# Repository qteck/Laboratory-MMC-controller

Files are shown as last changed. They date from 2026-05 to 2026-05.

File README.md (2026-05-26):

# Laboratory MMC controller

This system drives series-connected stack topologies. The core of the system is the controller board that implements STM32 for flow control and data processing. The board provides local and remote HMI, monitoring points for voltage and current, and additional functions such as PWM channels or a power supply terminal.

The system provides extended functionality through additional shields, such as a data acquisition shield for producing or reconstructing digital signals, a power supply board, and an encoder and display for local user input.

Functions: 
- Submodule UART Link 
- USB Data Link
- Voltage Monitoring 
- Current Monitoring 

Additional Functions: 
- PWM Channels
- 5V/3V3 Power Sources

PCB Shields:
- Data Acquisition (signal viewer)
- Power Supply (power booster)
- Encoder
- Display

## Ideal Laboratory Submodule

For the controller to be able to efficiently drive the submodules, the submodules need to implement a full-duplex UART communication protocol and accurate time metering. The used MCU also has to be capable of producing the control waveforms, such as the modulation sine wave and carrier triangular wave, for producing the control switching patterns. The time synchronization setting is essential for effective functioning and should be optimized by algorithmic sweeps through the stack. However, for simplicity and versatility, it is recommended to implement a synchronization input, giving an extra synchronization option, for example, for debugging purposes.

The submodules should be autonomous and function as decentralized units, implementing functions such as current and voltage metering on board, local capacitor management on board, and the submodule algorithm to define the stack behaviour, describing functions such as data propagation, frequency adjustment, scheduled events, and fault handling.

### Minimal Submodule Design

The minimal submodule design establishes the conversion features only: an MCU with half-bridge or full-bridge capabilities and a capacitor on board that connects over UART and synchronizes over an external pin. The capacitors can then be directly charged from the controller board, leaving out all the complex control problems.

## Simple System Architecture
System Architecture
## PCB Assembly
PCB Assembly
## Detailed System Architecture
Detailed System Architecture
## Real System View
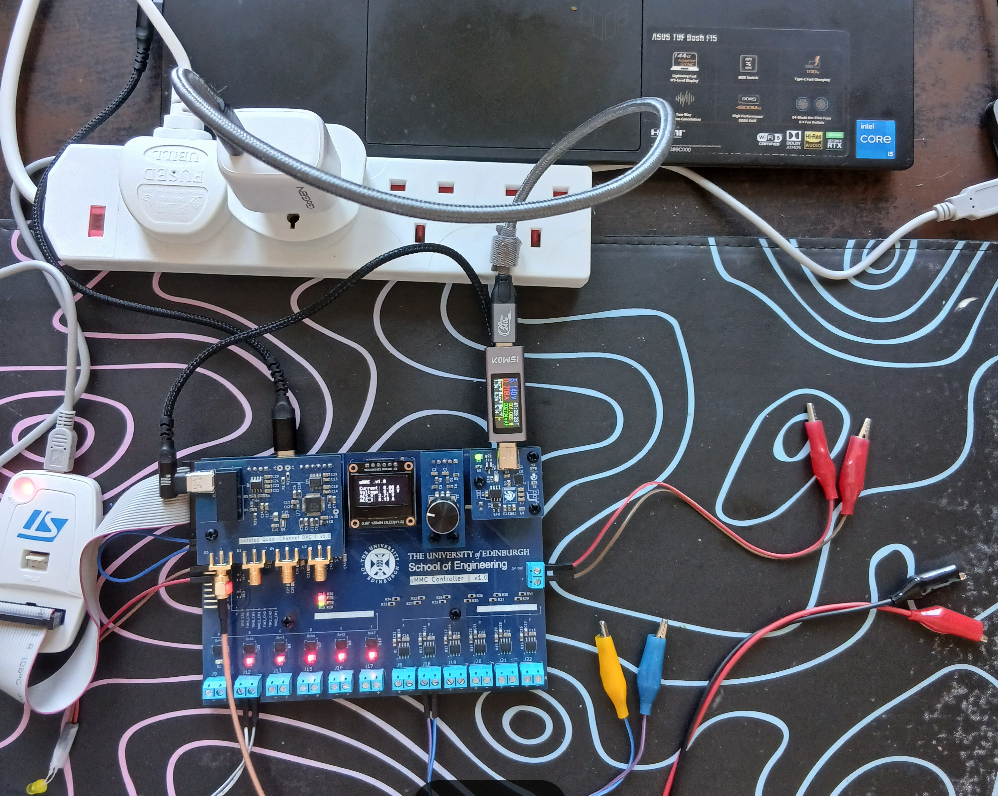
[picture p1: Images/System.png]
Real System View

## Model System View
Model System View

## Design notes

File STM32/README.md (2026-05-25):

# STM32H725VGTx

## Pinout

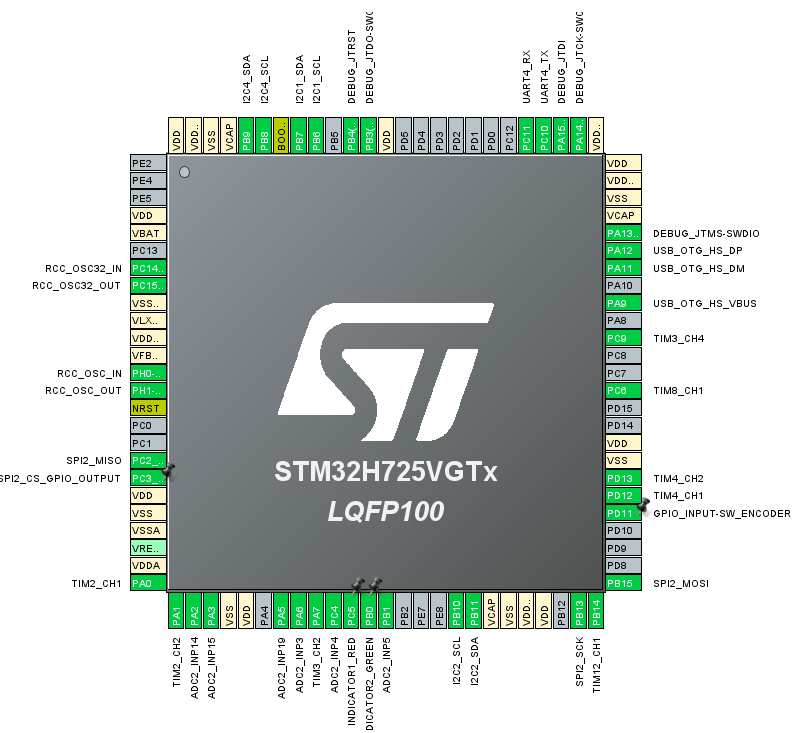
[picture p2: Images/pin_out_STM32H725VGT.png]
STM32H725VGTx pinout


## References

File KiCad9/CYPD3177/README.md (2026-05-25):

# Power Supply

The purpose of this module is to provide 5V@1A. The power negotiation is managed by the CYPD3177, which negotiates the power over the CC lines and triggers an alert if the negotiation for the selected power scenario fails.

The module features a load switch made of two back-to-back PMOS transistors, soft start, and inductive kickback protection.

## Improvement: 
To improve the modular USB power supply, a switchable display showing power consumption could be implemented, as well as means for remote power monitoring purposes over some digital protocol.

## Front Side 
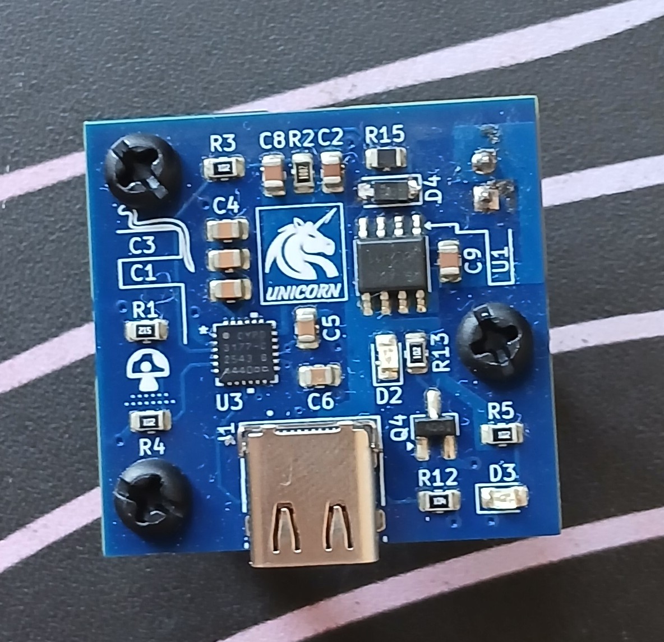
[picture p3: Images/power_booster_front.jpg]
controller front

## Back Side
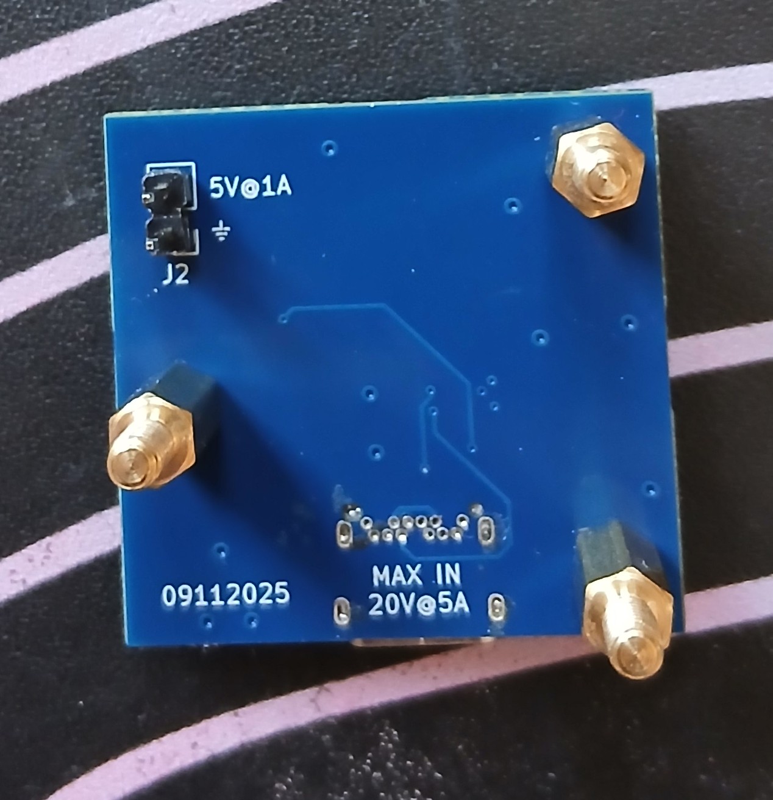
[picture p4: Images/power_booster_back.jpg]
controller back


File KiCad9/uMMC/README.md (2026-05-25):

# Laboratory MMC controller
The purpose of the controller is to drive series-connected stack topologies. This is achieved through a UART data connection, which is responsible for communicating variables such as the modulation index and submodule ID.

To achieve accurate switching, the submodules must be capable of real-time synchronisation and local generation of synchronous triangular carrier waveforms and sinusoidal modulation waveforms.

While the triangular carrier waveform is synchronised and common to all submodules, the modulation waveform has different amplitudes for each submodule. These amplitude offsets are calculated on the controller board and propagated through the UART data connection.

## Time Synchronisation  

### Time-Tuning Algorithm  

The time synchronisation can be achieved simply by propagating the reference time through the stack over UART. These times can then be compared on the controller, and the propagation delays can be compensated for.

### Synchronisation Signal  

Alternatively, for a simple implementation and high accuracy, the submodules can feature a synchronisation pin that would start the time, for example, on logic high.

## Initialisation

The stack is expected to be initialised by running firmware on the submodules that firstly passes the data sent down the chain, and secondly iterates a variable that counts the submodules.

Based on the number of submodules and symmetry of the arms, the number of modules per arm is obtained by division of two.

The offset values of the modulation index are then calculated based on the number of submodules present in the upper and lower arm. These offsets are then distributed over UART to each of the submodules.

## Front Side 
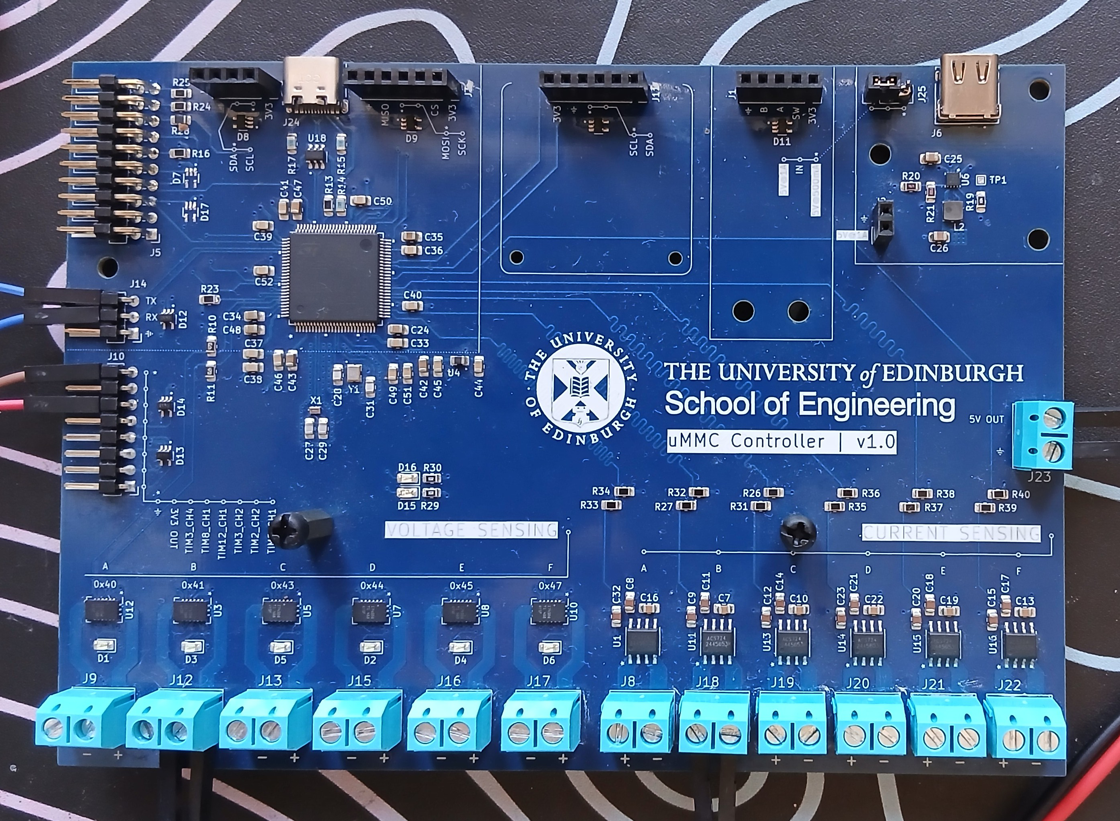
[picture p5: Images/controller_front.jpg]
controller front

## Back Side
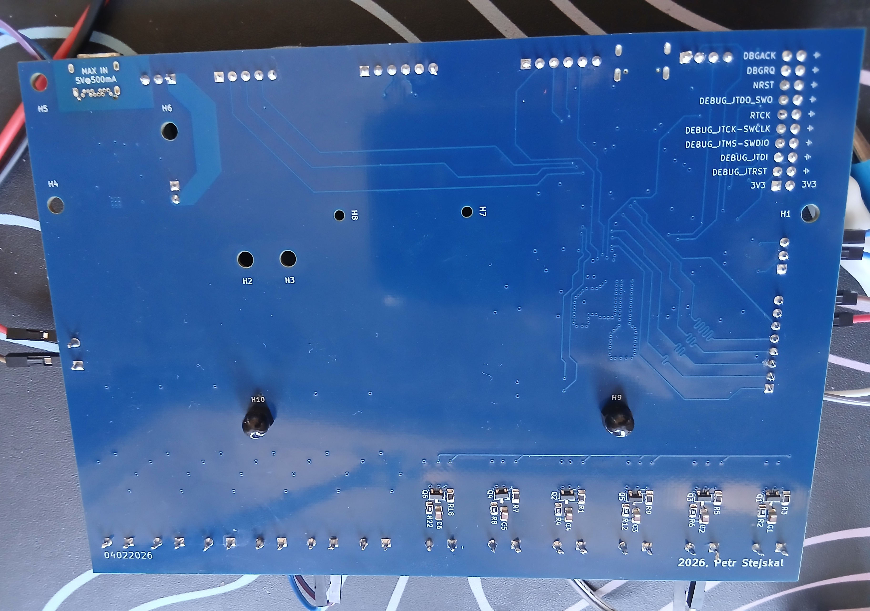
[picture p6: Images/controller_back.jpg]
controller back


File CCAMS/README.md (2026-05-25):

# Cloud Control and Monitoring System (CCAMS)

This is a cloud control and monitoring system implementing basic functionality. It uses the Web Serial API in Chrome.

Includes:
- jQuery
- Bootstrap
- Popper.js
- Web Serial API

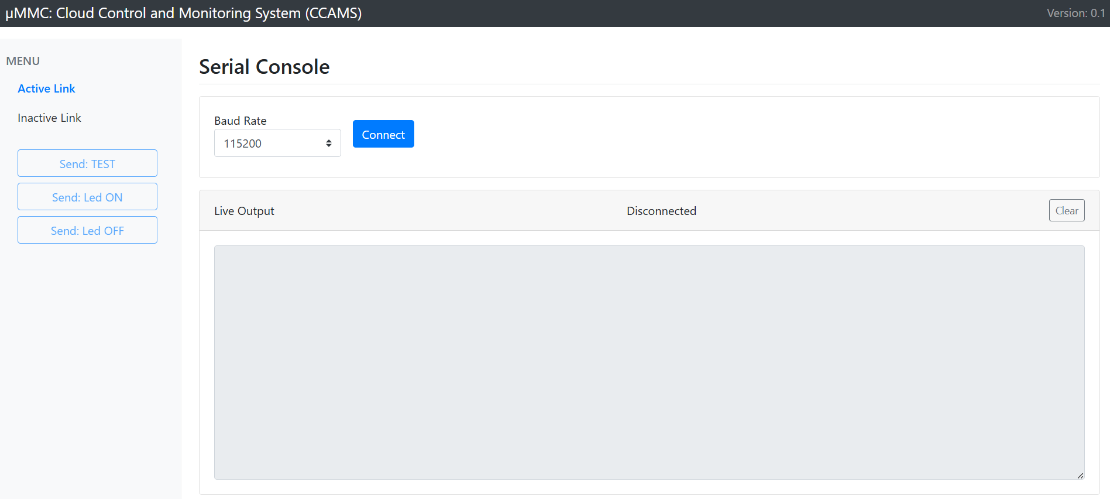
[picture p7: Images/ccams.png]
CCAMS


## References

- MDN Web Docs: Web Serial API  
  https://developer.mozilla.org/en-US/docs/Web/API/Web_Serial_API

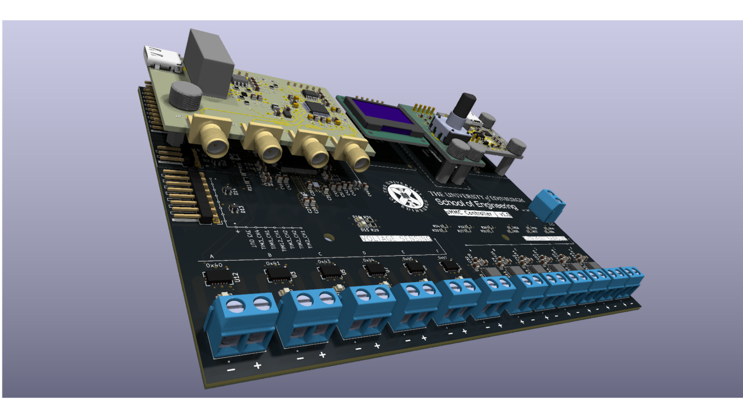
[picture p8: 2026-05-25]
KiCad9/uMMC/Images/900e9da2-3d48-431e-bf87-90206d79b5b3.png

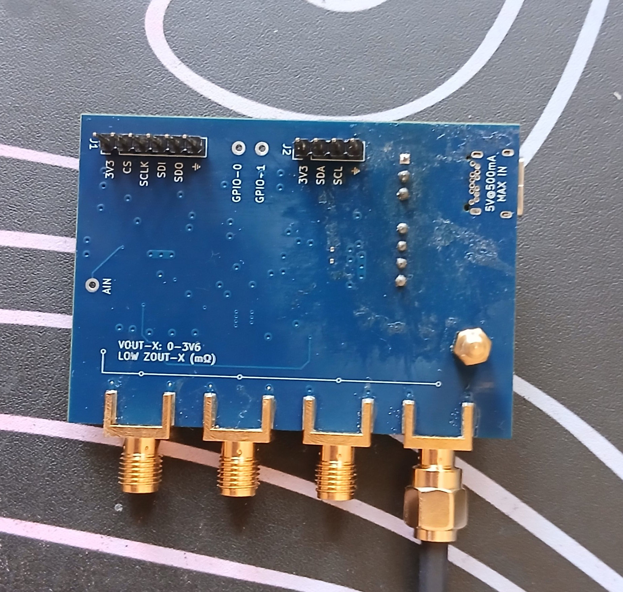
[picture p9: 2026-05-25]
Images/acquisition_back.jpg

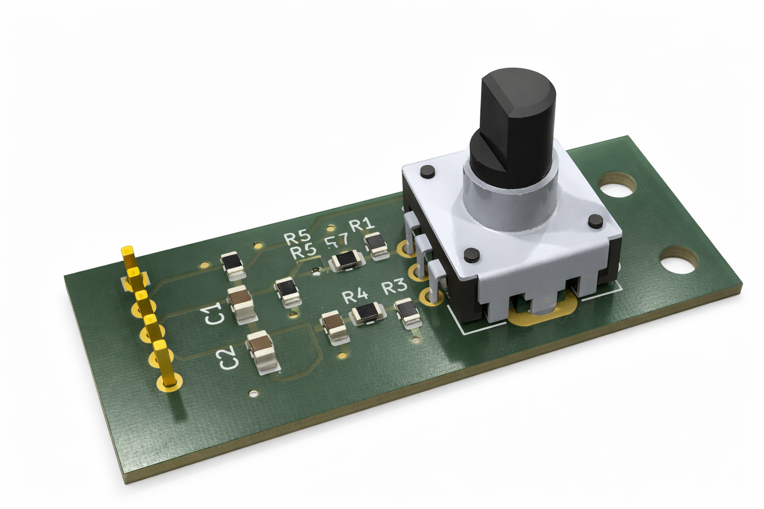
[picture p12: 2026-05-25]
KiCad9/uMMC/Images/encoder2.png

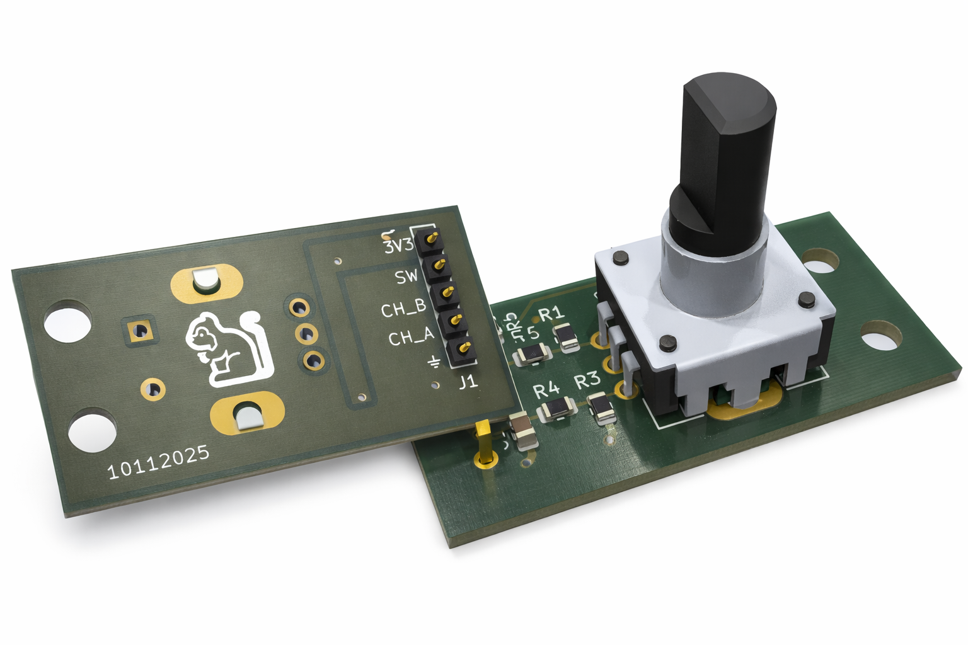
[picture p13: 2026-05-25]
KiCad9/uMMC/Images/encoder.png

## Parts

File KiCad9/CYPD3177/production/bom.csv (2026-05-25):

Designator | Footprint | Quantity | Value | LCSC Part #
C1, C3 | 1210 | 2 | 0.1u | C304007
C10 | 1210 | 1 | 3.3u | C575409
C2, C8, C9 | 1210 | 3 | 1u | C382212
C4 | 1210 | 1 | 1u | C304007
C5, C6 | 1210 | 2 | 330p | C5144765
D2 | 0805 | 1 | 5mA | C5349939
D3 | 0805 | 1 | 20mA | C84260
D4 | D_SOD-123FL | 1 | 10V | C551630
J1 | GCT_USB4056-03-A_REVA2 | 1 | USB4056-03-A_REVA2
J2, J3 | PinHeader_1x02_P2.54mm_Vertical | 2 | Conn_01x02 | C27985187
Q1, Q3 | SOT-23_Handsoldering | 2 | 2305-B | C22362821
Q4 | SOT-23_Handsoldering | 1 | NTR4503NT1G | C94763
R1, R4, R7, R8 | 1210 | 4 | 2k | C396544
R10, R15 | 1210 | 2 | 49.9k | C422286
R11, R13, R3 | 1210 | 3 | 1k | C3152371
R12 | 1210 | 1 | 100K | C910966
R14 | 1210 | 1 | 2.21K | C174501
R2 | 1210 | 1 | 10k | C3018181
R9 | 1210 | 1 | 0 | C3018186
RV1, RV2, RV3, RV4 | Potentiometer_Bourns_3296W_Vertical | 4 | 25K | C55264
TP1, TP2, TP3 | TestPoint_THTPad_2.0x2.0mm_Drill1.0mm | 3 | ~
TP10, TP11, TP12, TP4, TP5, TP6, TP7, TP8, TP9 | TestPoint_THTPad_2.0x2.0mm_Drill1.0mm | 9 | TestPoint
U1 | AO4805-MS | 1 | AO4805-MS | C3008143
U3 | QFN24_CYPD3177_INF | 1 | CYPD3177-24LQXQ | C2959321

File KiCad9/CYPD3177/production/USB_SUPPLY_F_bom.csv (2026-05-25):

Designator | Footprint | Quantity | Value | LCSC Part #
C1, C3, C4 | 0805 | 3 | 0.1u
C2 | 0805 | 1 | 3.3u
C5, C6 | 0805 | 2 | 330p
C8, C9 | 0805 | 2 | 1u
D2 | 0805 | 1 | 5mA
D3 | 0805 | 1 | 20mA
D4 | D_SOD-123 | 1 | 10V
J1 | GCT_USB4056-03-A_REVA2 | 1 | USB4056-03-A_REVA2
J2 | PinHeader_1x02_P2.54mm_Vertical | 1 | Conn_01x02
Q4 | SOT-23_Handsoldering | 1 | PJA3406_R1_00001
R1 | 0805 | 1 | 5k1
R12 | 0805 | 1 | 100K
R13, R3, R4, R5 | 0805 | 4 | 1K
R15 | 0805 | 1 | 49.9k
R2 | 0805 | 1 | 10k
U1 | SOP-8_3.9x4.9mm_P1.27mm | 1 | AO4805-MS | C3008143
U3 | QFN24_CYPD3177_INF | 1 | CYPD3177-24LQXQ | C2959321

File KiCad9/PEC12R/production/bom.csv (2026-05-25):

Designator | Footprint | Quantity | Value | LCSC Part #
C1, C2 | 0805 | 2 | 0.01u
J1 | PinHeader_1x05_P2.54mm_Vertical | 1 | Conn_01x05_Pin
R1, R2, R3, R4, R5 | 0805 | 5 | 10k
S1 | XDCR_PEC12R-4220F-S0024 | 1 | PEC12R-4220F

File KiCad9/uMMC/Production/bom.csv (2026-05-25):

Designator | Footprint | Quantity | Value | LCSC Part #
C1, C11, C12, C14, C15, C17, C18, C2, C20, C21, C23, C3, C32, C4, C5, C6, C8, C9 | 0805 | 18 | 0.1u
C10, C13, C16, C19, C22, C7 | 0805 | 6 | 1n
C24, C42, C43 | 0805 | 3 | 1u
C25 | 0805 | 1 | 10u
C26 | 0805 | 1 | 22u
C27, C29 | 0805 | 2 | 8p
C28, C31 | 0805 | 2 | 10p
C33, C36, C37, C38, C39, C40, C41, C44, C45, C46, C49, C50, C51, C52 | 0805 | 14 | 100n
C34, C48 | 0805 | 2 | 2.2u
C35, C47 | 0805 | 2 | 4.7u
D1, D15, D16, D2, D3, D4, D5, D6 | 0805 | 8 | 20mA
D10, D11, D12, D13, D14, D17, D7, D8, D9 | ESDALC6V1W5 | 9 | ESDA6V1W5
J1 | PinSocket_1x05_P2.54mm_Vertical | 1 | ENCODER
J10 | PinHeader_1x08_P2.54mm_Horizontal | 1 | PWM
J11 | PinSocket_1x06_P2.54mm_Vertical | 1 | I2C DISPLAY
J12, J13, J15, J16, J17, J18, J19, J20, J21, J22, J23, J8, J9 | CUI_TB002-500-02BE | 13 | TB002-500-02BE
J14 | PinHeader_1x03_P2.54mm_Horizontal | 1 | SM_UART
J2 | PinSocket_1x02_P2.54mm_Vertical | 1 | 5V@1A
J24 | GCT_USB4105-GF-A-SMD | 1 | USB4105-GF-A
J25 | PinHeader_1x03_P2.54mm_Vertical | 1 | Conn_01x03_Pin
J3 | PinSocket_1x06_P2.54mm_Vertical | 1 | SPI_DAC
J4 | PinSocket_1x04_P2.54mm_Vertical | 1 | I2C_DAC
J5 | PinHeader_2x10_P2.54mm_Horizontal | 1 | JTAG_20PIN
J6 | GCT_USB4056-03-A_REVA2 | 1 | USB4056-03-A_REVA2
L2 | IND_VLS3012CX-2R2M-1 | 1 | 2.2u
Q1, Q2, Q3, Q4, Q5, Q6 | SOT-23_DMP2123L_DIO | 6 | DMP2123L-7
R1, R16, R18, R23, R24, R25, R26, R27, R3, R31, R32, R33, R34, R35, R36, R37, R38, R39, R40, R5, R7, R9 | 0805 | 22 | 10k
R10, R11 | 0805 | 2 | 4.7k
R12, R2, R22, R29, R30, R4, R6, R8 | 0805 | 8 | 1K
R13 | 0805 | 1 | 33k
R14 | 0805 | 1 | 68k
R15, R17 | 0805 | 2 | 5.1k
R19 | 0805 | 1 | 100K
R20 | 0805 | 1 | 470K
R21 | 0805 | 1 | 150K
R28 | 0805 | 1 | 0
TP1 | TestPoint_Pad_1.0x1.0mm | 1 | PG
U1, U11, U13, U14, U15, U16 | ACS724LLCTR_2P5AB_T | 6 | ACS724LLCTR-2P5AB-T
U10, U12, U3, U5, U7, U8 | INA745BQWRELRQ1 | 6 | INA745BQWRELRQ1CT
U18 | USBLC6-2SC6 | 1 | USBLC6-2SC6
U4 | BLM21_TALL_MUR | 1 | BLM21HE601SN1L
U6 | DSG0008A_NV | 1 | TPS62162QDSGTQ1
U9 | LQPF_25VGT3_STM | 1 | STM32H725VGT3
X1 | XTAL_ECS-.327-7-16-C-TR | 1 | 32.768 kHz
Y1 | XTAL_ABM10AIG-24.000MHZ-8-3Z-T3 | 1 | 24 MHz

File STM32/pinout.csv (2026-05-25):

Position | Name | Type | Signal | Label
1 | PE2 | I/O
2 | PE4 | I/O
3 | PE5 | I/O
4 | VDD | Power
5 | VBAT | Power
6 | PC13 | I/O
7 | PC14-OSC32_IN | I/O | RCC_OSC32_IN
8 | PC15-OSC32_OUT | I/O | RCC_OSC32_OUT
9 | VSSSMPS | Power
10 | VLXSMPS | Power
11 | VDDSMPS | Power
12 | VFBSMPS | Power
13 | PH0-OSC_IN | I/O | RCC_OSC_IN
14 | PH1-OSC_OUT | I/O | RCC_OSC_OUT
15 | NRST | Reset
16 | PC0 | I/O
17 | PC1 | I/O
18 | PC2_C | I/O | SPI2_MISO
19 | PC3_C | Output | GPIO_Output | SPI2_CS_GPIO_OUTPUT
20 | VDD | Power
21 | VSS | Power
22 | VSSA | Power
23 | VREF+ | MonoIO
24 | VDDA | Power
25 | PA0 | I/O | TIM2_CH1
26 | PA1 | I/O | TIM2_CH2
27 | PA2 | I/O | ADC2_INP14
28 | PA3 | I/O | ADC2_INP15
29 | VSS | Power
30 | VDD | Power
31 | PA4 | I/O
32 | PA5 | I/O | ADC2_INP19
33 | PA6 | I/O | ADC2_INP3
34 | PA7 | I/O | TIM3_CH2
35 | PC4 | I/O | ADC2_INP4
36 | PC5 | Output | GPIO_Output | INDICATOR1_RED
37 | PB0 | Output | GPIO_Output | INDICATOR2_GREEN
38 | PB1 | I/O | ADC2_INP5
39 | PB2 | I/O
40 | PE7 | I/O
41 | PE8 | I/O
42 | PB10 | I/O | I2C2_SCL
43 | PB11 | I/O | I2C2_SDA
44 | VCAP | Power
45 | VSS | Power
46 | VDDLDO | Power
47 | VDD | Power
48 | PB12 | I/O
49 | PB13 | I/O | SPI2_SCK
50 | PB14 | I/O | TIM12_CH1
51 | PB15 | I/O | SPI2_MOSI
52 | PD8 | I/O
53 | PD9 | I/O
54 | PD10 | I/O
55 | PD11 | Input | GPIO_Input | GPIO_INPUT-SW_ENCODER
56 | PD12 | I/O | TIM4_CH1
57 | PD13 | I/O | TIM4_CH2
58 | VSS | Power
59 | VDD | Power
60 | PD14 | I/O
61 | PD15 | I/O
62 | PC6 | I/O | TIM8_CH1
63 | PC7 | I/O
64 | PC8 | I/O
65 | PC9 | I/O | TIM3_CH4
66 | PA8 | I/O
67 | PA9 | I/O | USB_OTG_HS_VBUS
68 | PA10 | I/O
69 | PA11 | I/O | USB_OTG_HS_DM
70 | PA12 | I/O | USB_OTG_HS_DP
71 | PA13(JTMS/SWDIO) | I/O | DEBUG_JTMS-SWDIO
72 | VCAP | Power
73 | VSS | Power
74 | VDDLDO | Power
75 | VDD | Power
76 | VDD33USB | Power
77 | PA14(JTCK/SWCLK) | I/O | DEBUG_JTCK-SWCLK
78 | PA15(JTDI) | I/O | DEBUG_JTDI
79 | PC10 | I/O | UART4_TX
80 | PC11 | I/O | UART4_RX
81 | PC12 | I/O
82 | PD0 | I/O
83 | PD1 | I/O
84 | PD2 | I/O
85 | PD3 | I/O
86 | PD4 | I/O
87 | PD5 | I/O
88 | VDD | Power
89 | PB3(JTDO/TRACESWO) | I/O | DEBUG_JTDO-SWO
90 | PB4(NJTRST) | I/O | DEBUG_JTRST
91 | PB5 | I/O
92 | PB6 | I/O | I2C1_SCL
93 | PB7 | I/O | I2C1_SDA
94 | BOOT0 | Boot
95 | PB8 | I/O | I2C4_SCL
96 | PB9 | I/O | I2C4_SDA
97 | VCAP | Power
98 | VSS | Power
99 | VDDLDO | Power
100 | VDD | Power

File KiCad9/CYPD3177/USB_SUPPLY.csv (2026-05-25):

Reference | Value | Qty | DIGIKEY PN | Customer Reference
C1,C3,C4 | 0.1u | 3 | 399-C0805F104K1RACAUTOCT-ND | USB_SUPPLY
C2 | 3.3u | 1 | 445-175569-1-ND | USB_SUPPLY
C5,C6 | 330p | 2 | 399-C0805C331K5RACTUCT-ND | USB_SUPPLY
C8,C9 | 1u | 2 | 478-KAF21KR72A105KUCT-ND | USB_SUPPLY
D2 | 5mA | 1 | 160-1427-1-ND | USB_SUPPLY
D3 | 20mA | 1 | 160-1426-1-ND | USB_SUPPLY
D4 | 10V | 1 | MMSZ10T1GOSCT-ND | USB_SUPPLY
J1 | USB4056-03-A_REVA2 | 1 | 2073-USB4056-03-ACT-ND | USB_SUPPLY
J2 | Conn_01x02 | 1 | 2057-PH1-02-UA-ND | USB_SUPPLY
Q4 | PJA3406_R1_00001 | 1 | 3757-PJA3406_R1_00001CT-ND | USB_SUPPLY
R1 | 5k1 | 1 | P5.1KADCT-ND | USB_SUPPLY
R2 | 10k | 1 | P16059CT-ND | USB_SUPPLY
R3,R4,R5,R13 | 1K,1k | 4 | P1.0KADCT-ND | USB_SUPPLY
R12 | 100K | 1 | P100KADCT-ND | USB_SUPPLY
R15 | 49.9k | 1 | 541-CRCW080549K9FKEAHPCT-ND | USB_SUPPLY
U1 | AO4805-MS | 1 | 785-1055-1-ND | USB_SUPPLY
U3 | CYPD3177-24LQXQ | 1 | 448-CYPD3177-24LQXQ-ND | USB_SUPPLY

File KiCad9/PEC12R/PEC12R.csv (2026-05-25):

Reference | Value | Qty | DIGIKEY PN | Customer Reference
C1,C2 | 0.01u | 2 | 399-C0805C103K5RACTUCT-ND | ENCODER
J1 | Conn_01x05_Pin | 1 | 2057-PH1-05-UA-ND | ENCODER
R1,R2,R3,R4,R5 | 10k | 5 | A126429CT-ND | ENCODER
S1 | PEC12R-4220F | 1 | PEC12R-4220F-S0024-ND | ENCODER

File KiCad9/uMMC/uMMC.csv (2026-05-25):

Reference | Value | Qty | DIGIKEY PN | Customer Reference
BOM3,BOM4,BOM5,BOM6,BOM7,BOM8,R28 | 0 | 7 | 541-2827-1-ND | uMMC
C27,C29 | 8p | 2 | 478-08055A8R0JAT2ACT-ND | uMMC
C28,C31 | 10p | 2 | 4713-GMC21CG100F50NTCT-ND | uMMC
C7,C10,C13,C16,C19,C22 | 1n | 6 | 399-17171-1-ND | uMMC
C1,C2,C3,C4,C5,C6,C8,C9,C11,C12,C14,C15,C17,C18,C20,C21,C23,C32 | 0.1u | 18 | 445-C2012X7R2A104K125DACT-ND | uMMC
C33,C36,C37,C38,C39,C40,C41,C44,C45,C46,C49,C50,C51,C52 | 100n | 14 | 1276-1003-1-ND | uMMC
C24,C42,C43 | 1u | 3 | 1276-1029-1-ND | uMMC
C34,C48 | 2.2u | 2 | 1276-2954-1-ND | uMMC
L2 | 2.2u | 1 | 445-180922-1-ND | uMMC
C35,C47 | 4.7u | 2 | 490-GRM21BR71C475KE51KCT-ND | uMMC
C25 | 10u | 1 | 1276-2872-1-ND | uMMC
C26 | 22u | 1 | 1276-CL21A226MAYNNNECT-ND | uMMC
D1,D2,D3,D4,D5,D6,D16 | 20mA | 7 | 160-1427-1-ND | uMMC
D15 | 20mA | 1 | 732-4986-1-ND | uMMC
Y1 | 24 MHz | 1 | 535-ABM10AIG-24.000MHZ-8-3Z-T3CT-ND | uMMC
X1 | 32.768 kHz | 1 | XC2842CT-ND | uMMC
R2,R4,R6,R8,R12,R22,R29,R30 | 1K | 8 | P1.0KADCT-ND | uMMC
R10,R11 | 4.7k | 2 | A129757CT-ND | uMMC
R15,R17 | 5.1k | 2 | 2019-RK73H2ATTD5101FCT-ND | uMMC
R1,R3,R5,R7,R9,R16,R18,R23,R24,R25,R26,R27,R31,R32,R33,R34,R35,R36,R37,R38,R39,R40 | 10k | 22 | 541-10.0KCCT-ND | uMMC
R13 | 33k | 1 | 541-33.0KCCT-ND | uMMC
R14 | 68k | 1 | 2019-RK73H2ATTD6802FCT-ND | uMMC
R19 | 100K | 1 | P100KADCT-ND | uMMC
R21 | 150K | 1 | 10-ERJ-UP6F1503VCT-ND | uMMC
R20 | 470K | 1 | 10-ERJ-UP6J474VCT-ND | uMMC
J3,J11 | I2C DISPLAY,SPI_DAC | 2 | 2057-RS1-06-G-ND | uMMC
J2 | 5V@1A | 1 | 2057-RS1-02-G-ND | uMMC
U1,U11,U13,U14,U15,U16 | ACS724LLCTR-2P5AB-T | 6 | 620-ACS724LLCTR-2P5AB-TCT-ND | uMMC
U4 | BLM21HE601SN1L | 1 | 490-BLM21HE601SN1LCT-ND | uMMC
J25 | Conn_01x03_Pin | 1 | 2057-PH1-03-UA-ND | uMMC
BOM10 | DFRobot - DFR0650 - Display | 1 | 1738-DFR0650-ND | uMMC
BOM11 | Display Header | 1 | 2057-PH1-06-UA-ND | uMMC
Q1,Q2,Q3,Q4,Q5,Q6 | DMP2123L-7 | 6 | DMP2123LDICT-ND | uMMC
J1 | ENCODER | 1 | 2057-RS1-05-G-ND | uMMC
D7,D8,D9,D10,D11,D12,D13,D14,D17 | ESDA6V1W5 | 9 | 497-7231-1-ND | uMMC
J4 | I2C_DAC | 1 | 2057-RS1-04-G-ND | uMMC
U3,U5,U7,U8,U10,U12 | INA745BQWRELRQ1CT | 6 | 296-INA745BQWRELRQ1CT-ND | uMMC
J5 | JTAG_20PIN | 1 | 2057-PH2RA-20-UA-ND | uMMC
BOM2 | Jumper | 1 | 732-2678-ND | uMMC
TP1 | PG | 1 | 738-RNCF0805DTE20R0CT-ND | uMMC
J10 | PWM | 1 | PH1RB-08-UA | uMMC
J14 | SM_UART | 1 | PH1RB-03-UA | uMMC
U9 | STM32H725VGT3 | 1 | 497-STM32H725VGT3-ND | uMMC
J8,J9,J12,J13,J15,J16,J17,J18,J19,J20,J21,J22,J23 | TB002-500-02BE | 13 | 102-6145-ND | uMMC
U6 | TPS62162QDSGTQ1 | 1 | 296-48202-1-ND | uMMC
J24 | USB4105-GF-A | 1 | 2073-USB4105-GF-ACT-ND | uMMC
J6 | USB4056-03-A_REVA2 | 1 | 2073-USB4056-03-ACT-ND | uMMC
U18 | USBLC6-2SC6 | 1 | 497-5235-1-ND | uMMC

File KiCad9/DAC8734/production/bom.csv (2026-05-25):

Designator | Footprint | Quantity | Value | LCSC Part #
C1, C10, C12, C3, C8, C9 | CP_EIA-2012-12_Kemet-R_HandSolder | 6 | 10u
C11, C13, C14, C2, C21, C23, C24, C4, C5, C6, C7 | 0805 | 11 | 0.1u
C15, C17, C18, C19, C20, C22, C25 | 0805 | 7 | 10u
J1 | PinHeader_1x06_P2.54mm_Vertical | 1 | Conn_01x06_Pin
J2 | PinHeader_1x04_P2.54mm_Vertical | 1 | Conn_01x04_Pin
J5 | GCT_USB4056-03-A_REVA2 | 1 | USB4056-03-A_REVA2
L1 | 1008 | 1 | 4.7u
PS1 | CONV_TEC_2-0921 | 1 | TEC_2-0921
R1, R2 | 0805 | 2 | 10k
R3 | 0805 | 1 | 80k
R4 | 0805 | 1 | 100k
R5, R6 | 0805 | 2 | 4.7k
U1, U2, U4, U5 | LINX_CONSMA020.062-G | 4 | CONSMA020.062-G
U10 | TLA2021IRUGR | 1 | TLA2021IRUGR
U3 | DBQ16_TEX | 1 | ISO7741FQDBQRQ1
U6 | TPS62745DSSR | 1 | TPS62745DSSR
U7 | QFP50P900X900X120-48N | 1 | DAC8734SPFBR | DAC8734SPFBR
U9 | TPT72617SO1R | 1 | TPT72617-SO1R

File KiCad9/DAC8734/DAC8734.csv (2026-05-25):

Reference | Value | Qty | DIGIKEY PN | Customer Reference
J5 | USB4056-03-A_REVA2 | 1 | 2073-USB4056-03-ACT-ND | DAC8734
U9 | TPT72617-SO1R | 1 | 5503-TPT72617-SO1RCT-ND | DAC8734
U10 | TLA2021IRUGR | 1 | 296-TLA2021IRUGRCT-ND | DAC8734
PS1 | TEC_2-0921 | 1 | 1951-1387-ND | DAC8734
U3 | ISO7741FQDBQRQ1 | 1 | 296-51207-1-ND | DAC8734
U7 | DAC8734SPFBR | 1 | 296-DAC8734SPFBRCT-ND | DAC8734
U1,U2,U4,U5 | CONSMA020.062-G | 4 | 343-CONSMA020.062-G-ND | DAC8734
J1 | Conn_01x06_Pin | 1 | 2057-PH1-06-UA-ND | DAC8734
J2 | Conn_01x04_Pin | 1 | 2057-PH1-04-UA-ND | DAC8734
L1,U6 | 4.7u,TPS62745DSSR | 2 | 490-10639-1-ND | DAC8734
R4 | 100k | 1 | 311-100KCRCT-ND | DAC8734
R3 | 80k | 1 | 541-CRCW080580K6FKEACCT-ND | DAC8734
R1,R2 | 10k | 2 | 541-10.0KCCT-ND | DAC8734
R5,R6 | 4.7k | 2 | A129757CT-ND | DAC8734
C15,C17,C18,C19,C20,C22,C25 | 10u | 7 | 1276-2872-1-ND | DAC8734
C1,C3,C8,C9,C10,C12 | 10u | 6 | 478-TCTP1C106M8RCT-ND | DAC8734
C13,C14,C21,C23,C24 | 0.1u | 5 | 478-KGM21NR71H104KTCT-ND | DAC8734
C2,C4,C5,C6,C7,C11 | 0.1u | 6 | 445-C2012X7R2A104K125DACT-ND | DAC8734

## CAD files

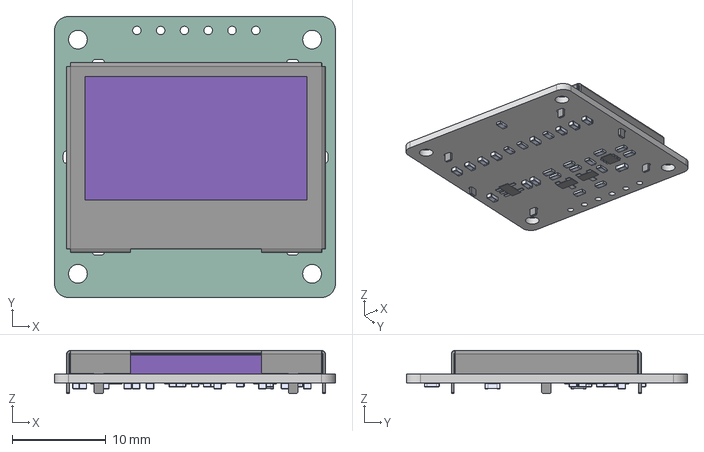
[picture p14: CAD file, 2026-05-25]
KiCad9/DFRobot_Display/3d/DFR0650_3D_STP/DFR0650.stp
30.0 x 30.0 x 4.60 mm

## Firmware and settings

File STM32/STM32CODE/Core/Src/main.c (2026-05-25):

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
/* Includes ------------------------------------------------------------------*/
#include "main.h"
#include "usb_device.h"

/* USER CODE BEGIN Includes */
#include <stdio.h>

#include "usbd_cdc_if.h"
extern USBD_HandleTypeDef hUsbDeviceHS;


#include "ssd1306.h"
#include "ssd1306_tests.h"
#include "ssd1306_fonts.h"

/* USER CODE END Includes */

ADC_HandleTypeDef hadc2;

CORDIC_HandleTypeDef hcordic;

CRC_HandleTypeDef hcrc;

FMAC_HandleTypeDef hfmac;

I2C_HandleTypeDef hi2c1;
I2C_HandleTypeDef hi2c2;
I2C_HandleTypeDef hi2c4;

SPI_HandleTypeDef hspi2;

TIM_HandleTypeDef htim2;
TIM_HandleTypeDef htim3;
TIM_HandleTypeDef htim4;
TIM_HandleTypeDef htim8;
TIM_HandleTypeDef htim12;

UART_HandleTypeDef huart4;

void SystemClock_Config(void);
void PeriphCommonClock_Config(void);
static void MPU_Config(void);
static void MX_GPIO_Init(void);
static void MX_I2C1_Init(void);
static void MX_I2C2_Init(void);
static void MX_SPI2_Init(void);
static void MX_TIM2_Init(void);
static void MX_TIM3_Init(void);
static void MX_TIM4_Init(void);
static void MX_TIM8_Init(void);
static void MX_TIM12_Init(void);
static void MX_UART4_Init(void);
static void MX_ADC2_Init(void);
static void MX_I2C4_Init(void);
static void MX_CORDIC_Init(void);
static void MX_CRC_Init(void);
static void MX_FMAC_Init(void);
/* USER CODE BEGIN 0 */

float voltage[3];
const float vref = 3.3f; // Voltage reference set by STM32H on VREF+
const uint32_t fs = 65535; // 16 bits ADC
float current2[3];
const float offset = 2.6f; // Datasheet: 2.5V, measured: ~2.6V
const float sensitivity = 0.8f; // Datasheet: 800mV per 1A


  uint8_t vbus[2];
  float vbus_real;

  uint8_t current[2];
  float current_real;



//ADC for ACS
uint32_t adc_buff[3];
uint8_t adc_ready = 0;

//UART4 - SBs
uint8_t rx_data[1];
uint8_t tx_data[1] = "t";

//screen
char buffer[40];
char buffer1[40];
char buffer2[40];
char buffer3[40];
volatile uint16_t encoder_value = 0;
volatile uint16_t encoder_last_value = 0;
volatile uint8_t encoder_changed = 0;

uint8_t switch_state;

void HAL_ADC_ConvCpltCallback(ADC_HandleTypeDef* hadc)
{
	adc_ready = 1;
}


void HAL_UART_RxCpltCallback(UART_HandleTypeDef *huart)
{
    if (huart->Instance == UART4)
    {
        HAL_UART_Transmit_IT(&huart4, tx_data, 1);
    }
}

void HAL_UART_TxCpltCallback(UART_HandleTypeDef *huart)
{
    if (huart->Instance == UART4)
    {
        HAL_UART_Receive_IT(&huart4, rx_data, 1);
    }
}

void HAL_TIM_IC_CaptureCallback(TIM_HandleTypeDef *htim)
{
    encoder_value = __HAL_TIM_GET_COUNTER(htim);
    encoder_changed = 1;
}

/* USER CODE END 0 */

/**
  * @brief  The application entry point.
  * @retval int
  */
int main(void)
{

  /* MPU Configuration--------------------------------------------------------*/
  MPU_Config();

  /* MCU Configuration--------------------------------------------------------*/

  /* Reset of all peripherals, Initializes the Flash interface and the Systick. */
  HAL_Init();

  /* Configure the system clock */
  SystemClock_Config();

  /* Configure the peripherals common clocks */
  PeriphCommonClock_Config();

  /* Initialize all configured peripherals */
  MX_GPIO_Init();
  MX_I2C1_Init();
  MX_I2C2_Init();
  MX_SPI2_Init();
  MX_TIM2_Init();
  MX_TIM3_Init();
  MX_TIM4_Init();
  MX_TIM8_Init();
  MX_TIM12_Init();
  MX_UART4_Init();
  MX_ADC2_Init();
  MX_I2C4_Init();
  MX_CORDIC_Init();
  MX_CRC_Init();
  MX_FMAC_Init();
  MX_USB_DEVICE_Init();
  /* Infinite loop */
  /* USER CODE BEGIN WHILE */

  /*s
  HAL_ADCEx_Calibration_Start(&hadc2, ADC_CALIB_OFFSET, ADC_SINGLE_ENDED);
  HAL_ADC_Start_IT(&hadc2);
  */


  HAL_TIM_PWM_Start(&htim3, TIM_CHANNEL_2);
  HAL_TIM_PWM_Start(&htim3, TIM_CHANNEL_4);



  ssd1306_Init();
  ssd1306_Fill(Black);



  HAL_TIM_Encoder_Start_IT(&htim4, TIM_CHANNEL_ALL);


  while (1)
  {





	  /*
	   *
	  HAL_UART_Transmit_IT(&huart4, tx_data, 1);
	   */

	  /**
	   * Selects the PWMx channel and defines the duty cycle.
	   *
	   */
	  __HAL_TIM_SET_COMPARE(&htim3, TIM_CHANNEL_2, 10000); // 50%
	  __HAL_TIM_SET_COMPARE(&htim3, TIM_CHANNEL_4, 10000); // 50%

	  /*
	   * Populating the buffer with available channels.
	   *
	   * The voltage readings are scaled down by half by voltage dividers.
	   * They need to multiply by 2.
	   *
	   */

	  HAL_ADC_Start_IT(&hadc2);
	  if(adc_ready == 1) {
		  adc_ready = 0;

		  for(int var = 0; var <= 2; var++){
			  adc_buff[var] = HAL_ADC_GetValue(&hadc2);
			  voltage[var] = 2*((adc_buff[var] * vref) / fs); // Multiplied by 2
			  current2[var] =(voltage[var]-offset)/sensitivity;
		  }
	  }



	  HAL_GPIO_TogglePin(GPIOB, GPIO_PIN_0);


	  /*
	   * Config Reset
	   *
	   *
	   */
		uint8_t configuration_write[2] = {0x00, 0x00};
		HAL_I2C_Mem_Write(&hi2c4, 0x41 << 1, 0x00, I2C_MEMADD_SIZE_8BIT, configuration_write, 2, HAL_MAX_DELAY);

		uint8_t configuration_read[2];
		HAL_I2C_Mem_Read(&hi2c4, (0x41 << 1), 0x0B,
						 I2C_MEMADD_SIZE_8BIT,
						 configuration_read, 2, HAL_MAX_DELAY);

	  /**
	   * Continuous Modes
	   * Current, Voltage and Temperature registers are updated continuously
	   * In single-shot mode, a trigger is required to start the measurement.
	   *
	   */

		uint8_t continuous_mode_write[2] = {0xF0, 0x00}; // Sets continuous mode for current/temp/bus_voltage
		HAL_I2C_Mem_Write(&hi2c4,
						  (0x41 << 1),
						  0x01,
						  I2C_MEMADD_SIZE_8BIT,
						  continuous_mode_write,
						  2,
						  HAL_MAX_DELAY);

		uint8_t continuous_mode_read[2]; // Reads the continuous mode settings
		HAL_I2C_Mem_Read(&hi2c4,
						 (0x41 << 1),
						 0x01,
						 I2C_MEMADD_SIZE_8BIT,
						 continuous_mode_read,
						 2,
						 HAL_MAX_DELAY);


	  	  /*
	  	   * VBUS measurement
	  	   * Conversion Factor: 3.125mV LSB
	  	   *
	  	   */

	  	  HAL_I2C_Mem_Read(&hi2c4,
	  	                   (0x41 << 1),
	  	                   0x05,   // VBUS register
	  	                   I2C_MEMADD_SIZE_8BIT,
						   vbus,
	  	                   2,
	  	                   HAL_MAX_DELAY);

	  	  uint16_t vbus_reading = (uint16_t)((vbus[0] << 8) | vbus[1]);
	  	  vbus_real = vbus_reading  * 0.003125f;


	  	  /*
	  	   * Current measurement
	  	   * Conversion Factor: 1.2mV LSB
	  	   *
	  	   */

	  	  HAL_I2C_Mem_Read(&hi2c4,
	  	                   (0x41 << 1),
	  	                   0x07,   // VBUS register
	  	                   I2C_MEMADD_SIZE_8BIT,
						   current,
	  	                   2,
	  	                   HAL_MAX_DELAY);

	  	  int16_t current_reading = (current[0] << 8) | current[1];
	  	  current_real = current_reading  * 0.0012f;



	      if (HAL_GPIO_ReadPin(GPIOD, GPIO_PIN_11) == GPIO_PIN_SET)
	      {
	          HAL_GPIO_WritePin(GPIOB, GPIO_PIN_0, GPIO_PIN_SET);
	          switch_state = 1;
	      } else {
	    	  HAL_GPIO_WritePin(GPIOB, GPIO_PIN_0, GPIO_PIN_RESET); // LD1 OFF
	    	  switch_state = 0;
	      }

		  ssd1306_SetCursor(6, 4);
		  ssd1306_WriteString("uMMC .v1.0", Font_7x10, White);

		  int whole = (int)current_real;
		  int frac = (int)((current_real - whole) * 100);

		  if (frac < 0) frac = -frac;

		  snprintf(buffer, sizeof(buffer), "Current: %d.%02d A", whole, frac);

		  ssd1306_SetCursor(6, 20);
		  ssd1306_WriteString(buffer, Font_7x10, White);



		  int whole1 = (int)vbus_real;
		  int frac1 = (int)((vbus_real - whole1) * 100);

		  if (frac1 < 0) frac1 = -frac1;

		  snprintf(buffer1, sizeof(buffer1), "Voltage: %d.%02d V", whole1, frac1);

		  ssd1306_SetCursor(6, 30);
		  ssd1306_WriteString(buffer1, Font_7x10, White);




		  int whole2 = (int)voltage[0];
		  int frac2 = (int)((voltage[0] - whole2) * 100);

		  if (frac2 < 0) frac2 = -frac2;

		  snprintf(buffer2, sizeof(buffer2), "ACS_V: %d.%02d V", whole2, frac2);

		  ssd1306_SetCursor(6, 40);
		  ssd1306_WriteString(buffer2, Font_7x10, White);



		  int whole3 = (int)current2[0];
		  int frac3 = (int)((current2[0] - whole3) * 100);

		  if (frac3 < 0) frac3 = -frac3;

		  snprintf(buffer3, sizeof(buffer3), "ACS_I: %d.%02d A", whole3, frac3);

		  ssd1306_SetCursor(6, 50);
		  ssd1306_WriteString(buffer3, Font_7x10, White);
		  ssd1306_UpdateScreen();



/*
	    HAL_GPIO_WritePin(GPIOB, GPIO_PIN_0, GPIO_PIN_SET);
	    HAL_Delay(250);
	    HAL_GPIO_WritePin(GPIOB, GPIO_PIN_0, GPIO_PIN_RESET);
	    HAL_Delay(250);
*/



    /* USER CODE END WHILE */

    /* USER CODE BEGIN 3 */
  }
  /* USER CODE END 3 */
}

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
 /* MPU Configuration */

void MPU_Config(void)
{
  MPU_Region_InitTypeDef MPU_InitStruct = {0};

  /* Disables the MPU */
  HAL_MPU_Disable();

  /** Initializes and configures the Region and the memory to be protected
  */
  MPU_InitStruct.Enable = MPU_REGION_ENABLE;
  MPU_InitStruct.Number = MPU_REGION_NUMBER0;
  MPU_InitStruct.BaseAddress = 0x0;
  MPU_InitStruct.Size = MPU_REGION_SIZE_4GB;
  MPU_InitStruct.SubRegionDisable = 0x87;
  MPU_InitStruct.TypeExtField = MPU_TEX_LEVEL0;
  MPU_InitStruct.AccessPermission = MPU_REGION_NO_ACCESS;
  MPU_InitStruct.DisableExec = MPU_INSTRUCTION_ACCESS_DISABLE;
  MPU_InitStruct.IsShareable = MPU_ACCESS_SHAREABLE;
  MPU_InitStruct.IsCacheable = MPU_ACCESS_NOT_CACHEABLE;
  MPU_InitStruct.IsBufferable = MPU_ACCESS_NOT_BUFFERABLE;

  HAL_MPU_ConfigRegion(&MPU_InitStruct);
  /* Enables the MPU */
  HAL_MPU_Enable(MPU_PRIVILEGED_DEFAULT);

}

/**
  * @brief  This function is executed in case of error occurrence.
  * @retval None
  */
void Error_Handler(void)
{
  /* USER CODE BEGIN Error_Handler_Debug */
  /* User can add his own implementation to report the HAL error return state */
  __disable_irq();
  while (1)
  {
  }
  /* USER CODE END Error_Handler_Debug */
}
#ifdef USE_FULL_ASSERT
/**
  * @brief  Reports the name of the source file and the source line number
  *         where the assert_param error has occurred.
  * @param  file: pointer to the source file name
  * @param  line: assert_param error line source number
  * @retval None
  */
void assert_failed(uint8_t *file, uint32_t line)
{
  /* USER CODE BEGIN 6 */
  /* User can add his own implementation to report the file name and line number,
     ex: printf("Wrong parameters value: file %s on line %d\r\n", file, line) */
  /* USER CODE END 6 */
}
#endif /* USE_FULL_ASSERT */

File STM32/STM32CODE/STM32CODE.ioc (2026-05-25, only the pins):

Mcu.UserName=STM32H725VGTx
PA0.Signal=S_TIM2_CH1_ETR
PA1.Signal=S_TIM2_CH2
PA11.Signal=USB_OTG_HS_DM
PA12.Signal=USB_OTG_HS_DP
PA13(JTMS/SWDIO).Signal=DEBUG_JTMS-SWDIO
PA14(JTCK/SWCLK).Signal=DEBUG_JTCK-SWCLK
PA15(JTDI).Signal=DEBUG_JTDI
PA2.Signal=ADCx_INP14
PA3.Signal=ADCx_INP15
PA5.Signal=ADCx_INP19
PA6.Signal=ADCx_INP3
PA7.Signal=S_TIM3_CH2
PA9.Signal=USB_OTG_HS_VBUS
PB0.GPIO_Label=INDICATOR2_GREEN
PB0.Signal=GPIO_Output
PB1.Signal=ADCx_INP5
PB10.Signal=I2C2_SCL
PB11.Signal=I2C2_SDA
PB13.Signal=SPI2_SCK
PB14.Signal=S_TIM12_CH1
PB15.Signal=SPI2_MOSI
PB3(JTDO/TRACESWO).Signal=DEBUG_JTDO-SWO
PB4(NJTRST).Signal=DEBUG_JTRST
PB6.Signal=I2C1_SCL
PB7.Signal=I2C1_SDA
PB8.Signal=I2C4_SCL
PB9.Signal=I2C4_SDA
PC10.Signal=UART4_TX
PC11.Signal=UART4_RX
PC14-OSC32_IN.Signal=RCC_OSC32_IN
PC15-OSC32_OUT.Signal=RCC_OSC32_OUT
PC2_C.Signal=SPI2_MISO
PC3_C.GPIO_Label=SPI2_CS_GPIO_OUTPUT
PC3_C.Signal=GPIO_Output
PC4.Signal=ADCx_INP4
PC5.GPIO_Label=INDICATOR1_RED
PC5.Signal=GPIO_Output
PC6.Signal=S_TIM8_CH1
PC9.Signal=S_TIM3_CH4
PD11.GPIO_Label=GPIO_INPUT-SW_ENCODER
PD11.Signal=GPIO_Input
PD12.Signal=S_TIM4_CH1
PD13.Signal=S_TIM4_CH2
PH0-OSC_IN.Signal=RCC_OSC_IN
PH1-OSC_OUT.Signal=RCC_OSC_OUT

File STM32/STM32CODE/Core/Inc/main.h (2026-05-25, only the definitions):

#define SPI2_CS_GPIO_OUTPUT_Pin GPIO_PIN_3
#define SPI2_CS_GPIO_OUTPUT_GPIO_Port GPIOC
#define INDICATOR1_RED_Pin GPIO_PIN_5
#define INDICATOR1_RED_GPIO_Port GPIOC
#define INDICATOR2_GREEN_Pin GPIO_PIN_0
#define INDICATOR2_GREEN_GPIO_Port GPIOB
#define GPIO_INPUT_SW_ENCODER_Pin GPIO_PIN_11
#define GPIO_INPUT_SW_ENCODER_GPIO_Port GPIOD

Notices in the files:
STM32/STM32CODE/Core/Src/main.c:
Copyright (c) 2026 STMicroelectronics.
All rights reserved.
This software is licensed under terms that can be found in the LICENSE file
